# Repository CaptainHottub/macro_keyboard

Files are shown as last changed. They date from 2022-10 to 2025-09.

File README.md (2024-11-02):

# macro_keyboard

13-Key USB Macro Keyboard using the [KB2040 Kee Boar Driver][KB2040]

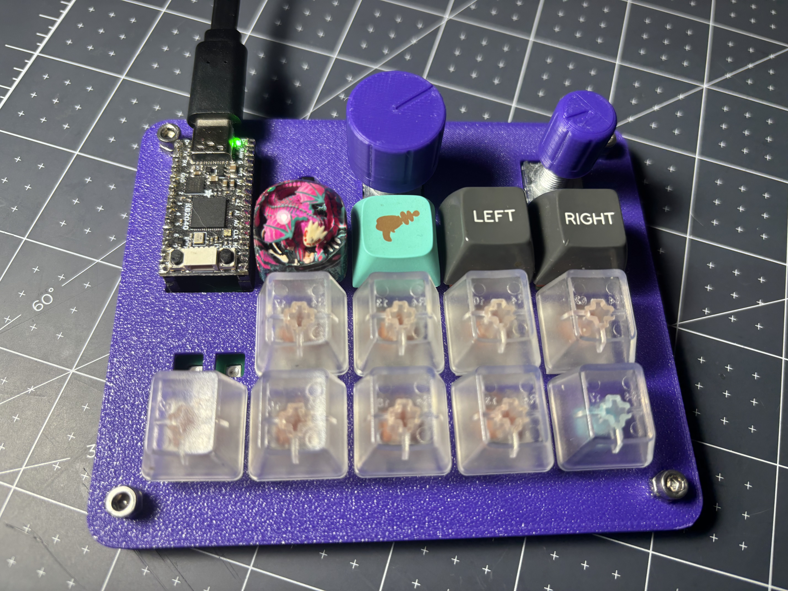
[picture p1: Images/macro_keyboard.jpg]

## Features
- The KB2040 MC communicates with the Python driver that runs on your computer
- The Python driver is fully customizable with the capability for application specific macros
- The Python driver allows for special scripts and complex macros. Anything you can think of.
- 3x4 Grid with 12 keys and 1 mode button
- 2 Rotary encoders with buttons
- 15 Addressable RGB LED backlights.
- South Facing LED and sockets
- KAILH hot swap sockets
- Unlimited layers and key combinations

## Getting Started
macro_keyboard V2.2x was designed to use the [Adafruit KB2040 - RP2040 Kee Boar Driver][KB2040], which has the same shape as the Arduino Pro Micro, so you could use any Arduino Pro Micro shaped MC in this macro_keyboard.
> If you use a different micro controller, you will have to change the pins in the MC code.

The KB2040 currently runs [CircuitPython](https://circuitpython.org/) version 8.2.9, but should work with anything newer.

#### Dependencies
If you are on Linux want to use the Media Controller macros you will you will need to install this package:
`sudo apt install libdbus-1-dev`

### KB2040 Setup
You will need to install CircuitPython on your KB2040 and to do so, follow Adafruit's excellent guide how to do exactly that: https://learn.adafruit.com/adafruit-kb2040/circuitpython

Once you get CircuitPython running on your KB2040, you will need to add a couple of libraries to it.
The Libraries that you will need are: 
- adafruit_hid
- adafruit_ticks.mpy
- neopixel.mpy

You can find them and the instructions to install them in the **CircuitPython Libraries** section of Adafruits KB2040 guide: https://learn.adafruit.com/adafruit-kb2040/circuitpython-libraries
You will find the libraries in the [**CircuitPython Library Bundle**](https://circuitpython.org/libraries)

Move the `code.py` file found in `src/Microcontroller/` onto the KB2040, then the KB2040 should do a soft reboot and start running that code.

### Python Driver Setup
The driver is a python script that connects to the comport that the KB2040 is connected to when plugged in via USB.  Once it connects to the comport, it waits for a "message" from the KB2040.  The "message" is sent when a button is released or an encoder changes position by turning.

The driver use [Python 3.12](https://www.python.org/downloads/)  or newer. Instruction on how to install Python can be found here: https://wiki.python.org/moin/BeginnersGuide/Download

To download the driver you can clone the repo or download a .zip of it:

    git clone https://github.com/CaptainHottub/macro_keyboard.git

You will need to install all the Python libraries listed in the `requirements.txt` file. Install using:

    pip install -r requirements.txt
In the `config.yaml` file you can find config options for:
Logging level, (INFO or DEBUG)

    logging: True 
    logging_level: DEBUG

Log Folder

    enter code log_folder: True
    log_folder_path: "" # The direct path
    log_folder_path_relative: "/logs" # relative from /macro_keyboard/

System Tray Icon

    system_tray_icon: True  
    # The direct path
    system_tray_icon_image_path: ""  
    # relative from /macro_keyboard/
    system_tray_icon_image_path_relative: "/Images/pythonIcon.ico"  

Connection Notification

    connected_notification: True  
    # in seconds
    notification_time: 2

Spotify auto start

    spotify_auto_start: False

Everything in the `config.yaml` file can be changed, you can add or remove whatever you want.

To run it you need to run the `macro_driver.py` in a terminal:

    python -u "/macro_keyboard/src/Driver/macro_driver.py"

### Assembling the PCB
Soldering all the components to the PCB can be a little difficult as I did chose some pretty small components, especially the LED's and diodes.
The production Gerber zip file for the PCB is in `src/PCB/Macro_PCB_2.2.x_Production_Gerber`, which you can submit to JLCPCB to get made.
The Bill Of Material is at  `/src/macro_keyboard_BOM.csv`. Most parts can be sourced from DigiKey.

There is a `macro_keyboard.step` that should help with any questions on component orientation.

**Bottom Mount Components**
- 13 KAILH Hot Swap Sockets
- 12 Diodes
- 15 SK6812-E RGB LEDS
- 330 OHM Resistor for LED Data Pin

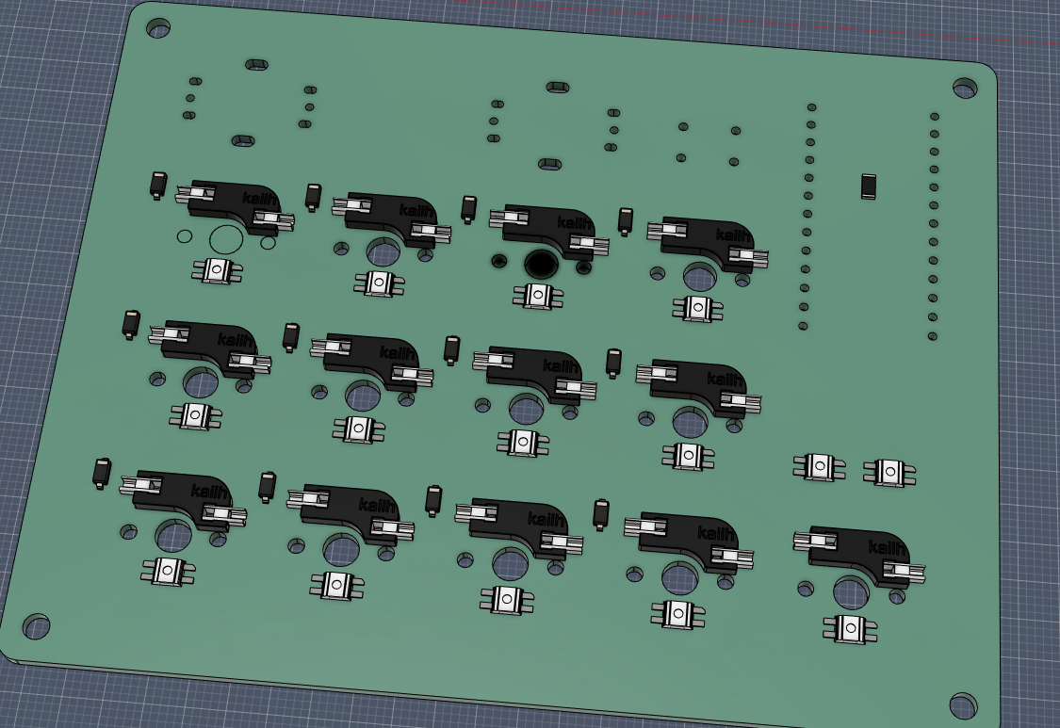
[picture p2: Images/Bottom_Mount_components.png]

> **Pay close attention to the position of the diode and especially the LED**

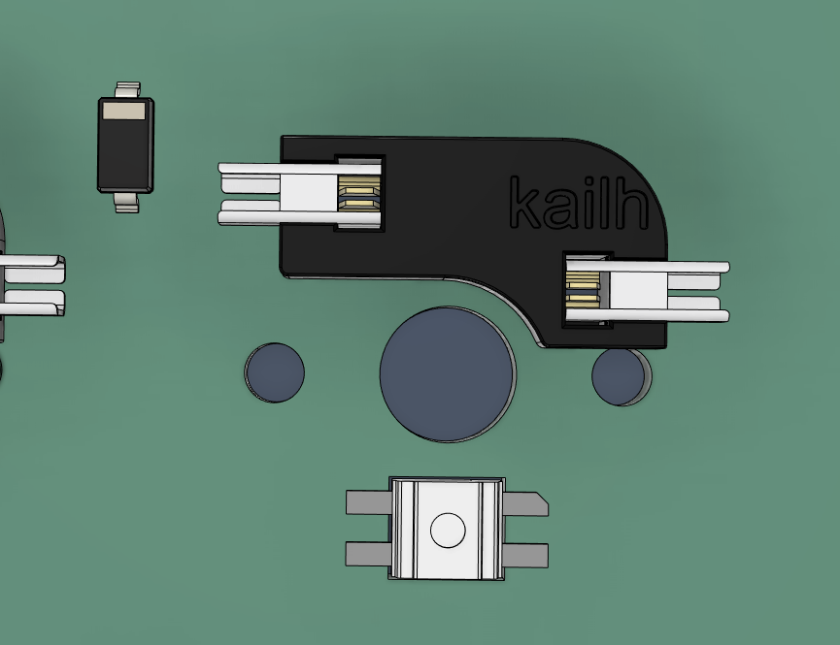
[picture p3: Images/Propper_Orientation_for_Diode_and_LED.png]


**Top Mount Components**
- KB2040
- 6x6mm Tactile Switch
- 2x Rotary Encoders (Is not necessary if you don't want it.)

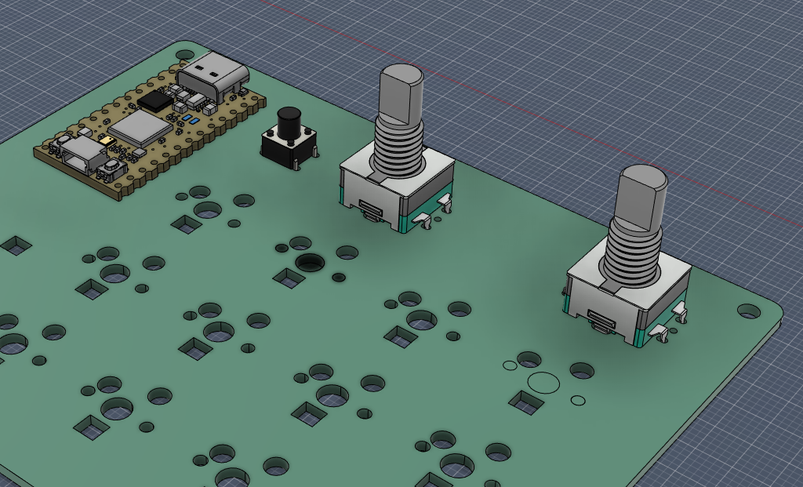
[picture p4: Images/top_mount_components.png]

If done properly any MX compatible key switch should just slide into each socket. The PCB is compatible with 3-pin and 5-pin key switches.

**Assembled PCB**

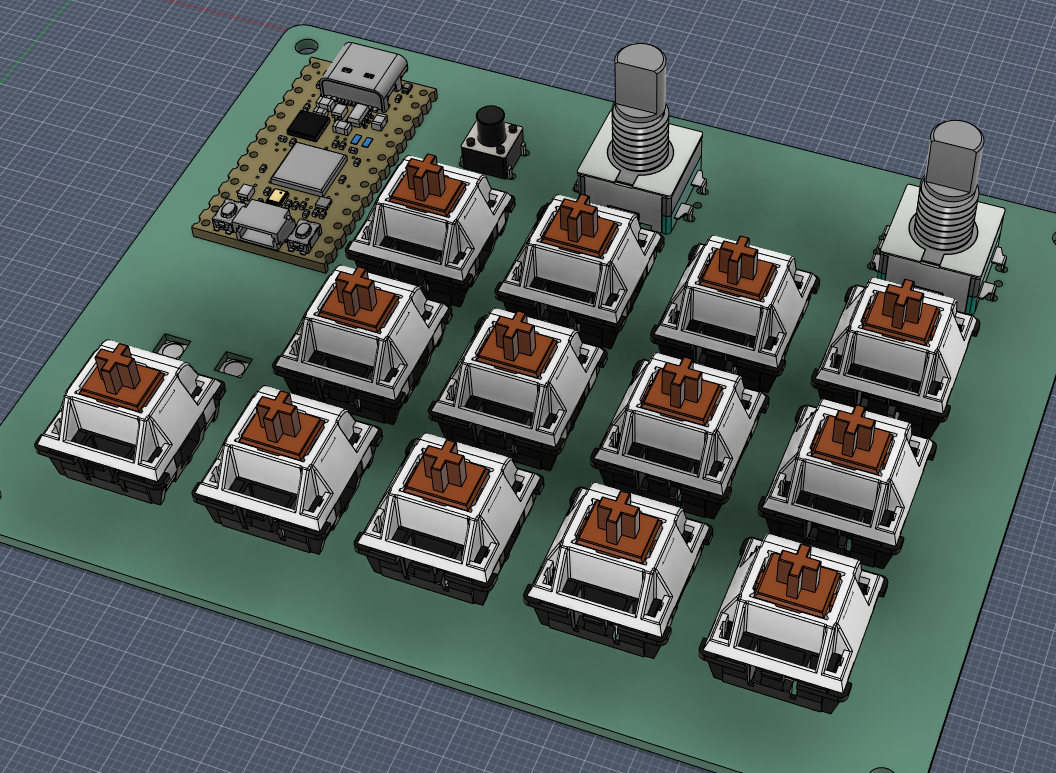
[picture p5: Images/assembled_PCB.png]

You should now have a fully assembles macro_keyboard that's ready to run. :)
It just needs a case.

### 3D Printed Case
Top half of the case

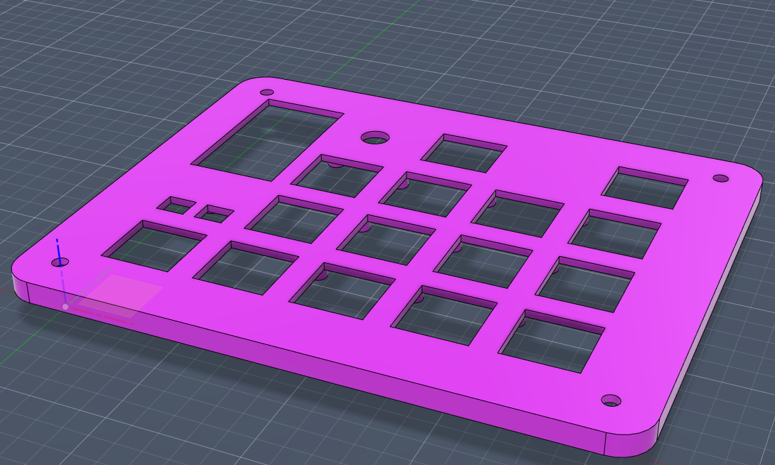
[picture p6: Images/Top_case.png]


The top half also serves as a plate that the keys snap into.

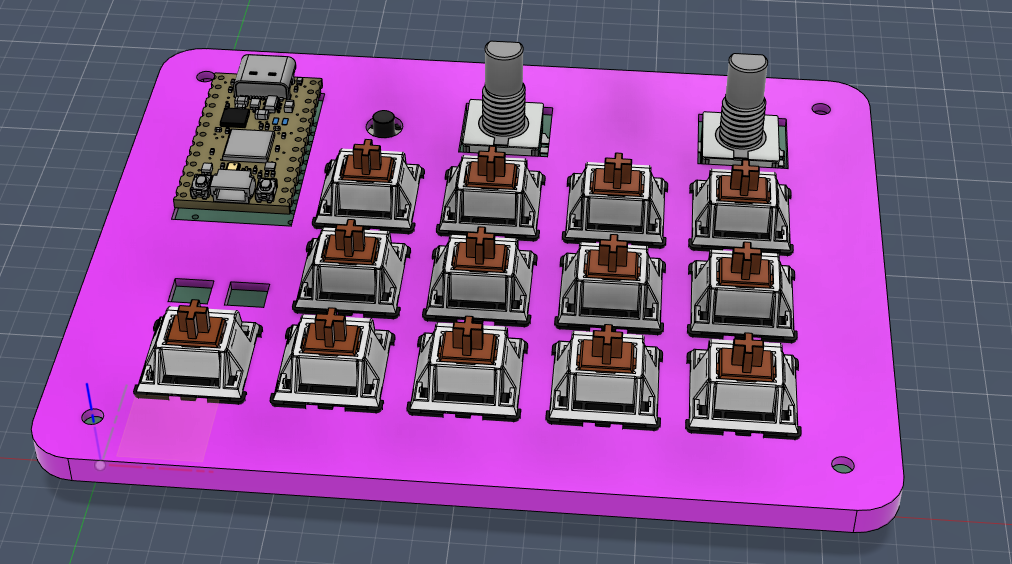
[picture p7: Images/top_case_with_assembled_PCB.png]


The bottom case on the left is called; `Bottom_Case_with_hole_V2.stl`, and the bottom case on the left is called; `Bottom_Case_No_Hole_V2.stl`

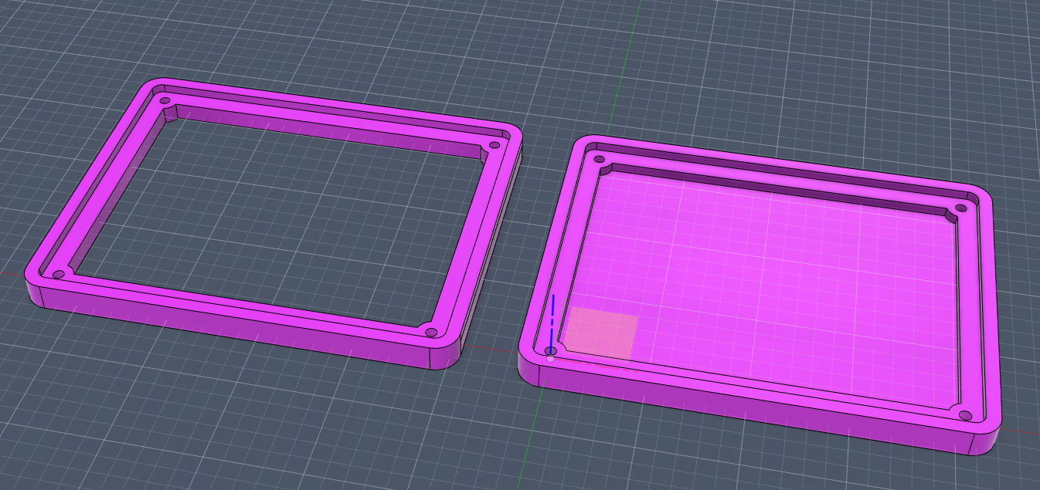
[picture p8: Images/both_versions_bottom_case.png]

The case uses 4 M3x12mm screws to secure it together, but it does support M3x10mm screws.

### Macro Examples
There are multiple macros that will work when you initially setup the driver. A couple of them are more complex then just keystrokes.
There are two groups of macro that I use the most, the first "group" is to control Spotify, the second "group" is to change and move apps across virtual desktops.

#### Spotify Macros
These macros use different code for different Operation Systems, because the Windows code wasn't compatible with Linux.
The prepacked macros involving Spotify are:

```python
####################################### Encoder 1 ########################################
match [app, encoder_data['Id'], encoder_data['Value'], layers]:
	case [_, 1, "RL", []]:	# Rotate Left
		logger.debug('VolumeDown')
		threading.Thread(target=Spotify.event_handler, args=('VolumeDown',)).start()
	case [_, 1, "RR", []]:	# Rotate Right
		logger.debug('VolumeUp')
		threading.Thread(target=Spotify.event_handler, args=('VolumeUp',)).start()
	case [_, 1, "RLB", []]:	# Rotate Left with Button
		logger.debug('Back5s')
		threading.Thread(target=Spotify.event_handler, args=('Back5s',)).start()
	case [_, 1, "RRB", []]:	# Rotate Right with Butotn
		logger.debug('Forward5s')
		threading.Thread(target=Spotify.event_handler, args=('Forward5s',)).start()

####################################### Buttons ########################################
match [app, mode, event_data['Button_id'], layers]:
	case [_, mode, 2, []]: # button 2
		logger.debug("Btn 2, no layers")
		threading.Thread(target=Spotify.press, args=()).start()
	case [_, mode, 2, [3, 4]]: # button 2 while button 3 and 4 are held
		logger.debug("Moves Spotify to the current virtual Desktop")
		threading.Thread(target=Spotify.move_spotify_window, args=('Current',)).start()    
	case [_, mode, 2, [3]]: # button 2 while button 3 is held
		logger.debug("Moves Spotify to the virtual Desktop on the left")
		threading.Thread(target=Spotify.move_spotify_window, args=('Left',)).start()    
	case [_, mode, 2, [4]]: # button 2 while button 4 is held
		logger.debug("Moves Spotify to the virtual Desktop on the right")
		threading.Thread(target=Spotify.move_spotify_window, args=('Right',)).start()   
	case [_, mode, 2, [1]]: # button 2 while button 1 is held
		logger.debug("Btn 2 and btn 1 as layer")
		threading.Thread(target=FireFox.press, args=()).start()
```
The macro I use the most is Spotify.press() which is attached to Button 2.
It works exactly like Apple's EarPods or there AirPods, where 1 press will play/pause, 2 presses will skip to the next song and 3 presses goes to the previous song.
On Linux it uses the `org.mpris.MediaPlayer2`  dbus interface to control media players.
On Windows it uses `pywinauto`  to connect to Spotify and send keyboard inputs.

## Inspiration
All of this was inspired by Ryan Bates and his [Macro Keyboard Video][video-inspiration]
[Website][retrobuilds2]

## License, Copyright, and Legal
All software and hardware designs in this repository are licensed under the [Creative Commons Attribution-NonCommercial 4.0 International][cc-by-nc] license.
[][cc-by-nc]

[cc-by-nc]: https://creativecommons.org/licenses/by-nc/4.0/
[cc-by-nc-image]: https://licensebuttons.net/l/by-nc/4.0/88x31.png

[retrobuilds]: http://www.retrobuiltgames.com/the-build-page/macro-keyboard-v2-0/ 
[retrobuilds2]: https://github.com/retrobuiltRyan/MacroKeyboardV2
[video-inspiration]: https://www.youtube.com/watch?v=IDlcxLQ1SbY
[KB2040]: https://www.adafruit.com/product/5302

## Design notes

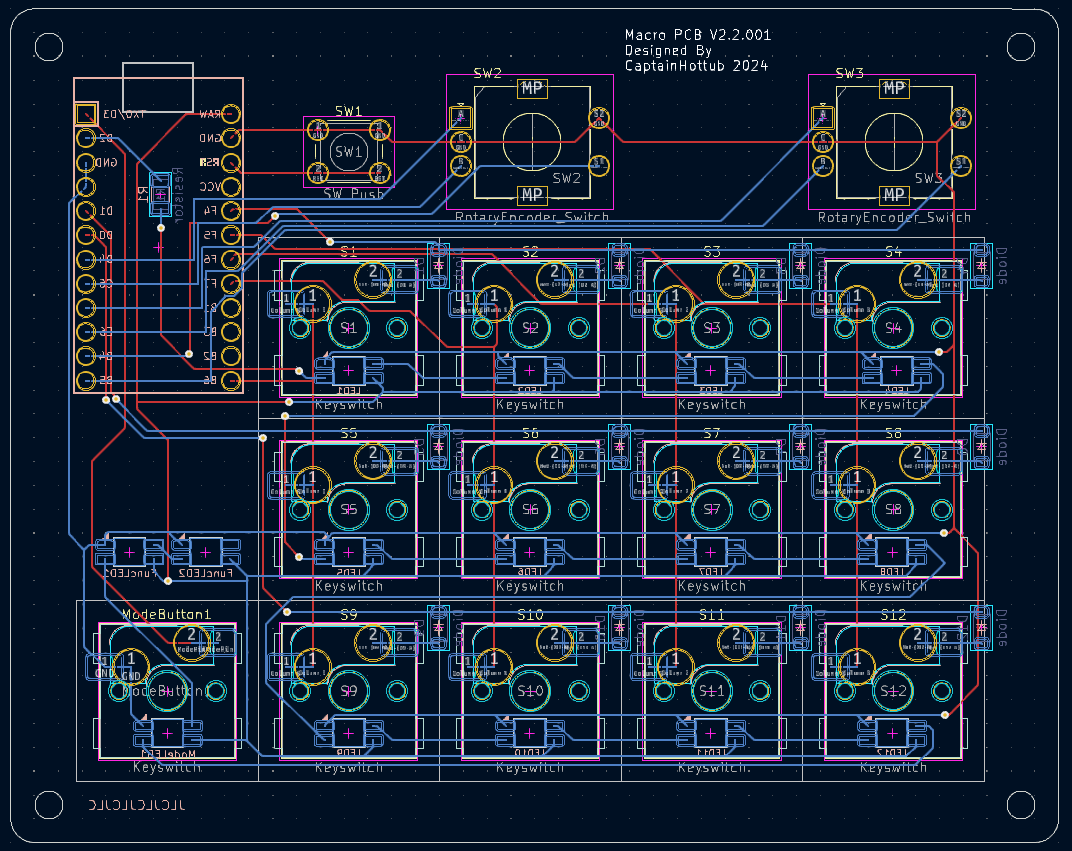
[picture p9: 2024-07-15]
Images/PCB_screenshot.png

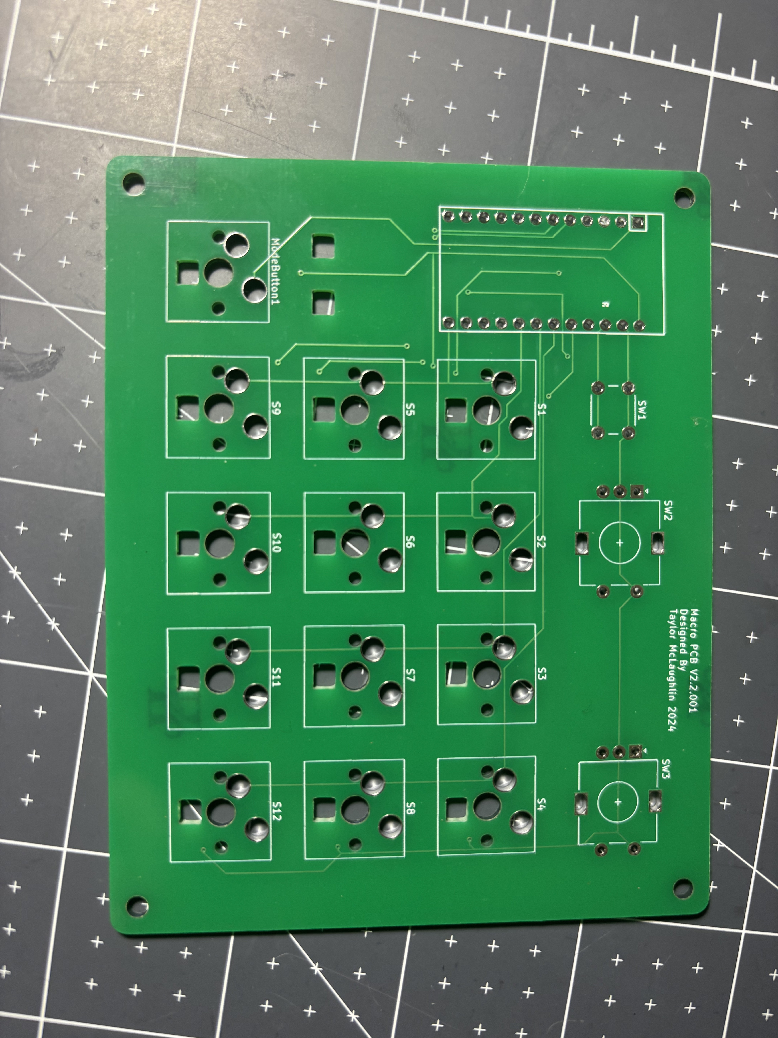
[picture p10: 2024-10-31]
Images/pcb.jpg

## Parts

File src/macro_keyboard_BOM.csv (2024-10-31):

Index | Quantity | Description | Vender | Vendor Part Number | Unit Price | Extended Price | Notes
1 | 1 | Adafruit KB2040 - RP2040 Kee Boar Driver | DigiKey | 1528-5302-ND | 13.14 | 13.14
2 | 1 | macro_keyboard v2.2.x PCB | -
3 | 13 | MX Cherry Keyswitch | - |  |  |  | 1 | 1 can be any MX compatible keyswitch
4 | 13 | Cherry MX Keycap | - |  |  |  | 1 | 2 any 6x6mm tactile switch will work
5 | 2 | Rotary encoder with Switch | DigiKey | 987-1398-ND | 4.62 | 9.24 |  | 3 This DigiKey listing comes in packs of 10
6 | 1 | SWITCH TACTILE SPST-NO 0.05A 12V | DigiKey | 679-2443-ND | 0.69 | 0.69 | 2 | 4 This DigiKey listing comes in packs of 20
7 | 2 | 1x12 Header 0.1” pitch | DigiKey | S6100-ND | 1.42 | 2.84
8 | 12 | Diode, small, 100V 300MA SOD123 | DigiKey | 1N4148W-13FDICT-ND | 0.15 | 1.8
9 | 1 | RES 330 OHM 5% 1/4W 1206 | DigiKey | RMCF1206JT330RCT-ND | 0.16 | 0.16
10 | 2 | SK6812-E RGB LEDS - 10PC | DigiKey | 1528-4960-ND | 4.62 | 9.24 | 3
11 | 1 | 3D Printed Case - Custom - | -
12 | 1 | KAILH MX HotSwap Sockets - 20PC | DigiKey | 1528-4958-ND | 7.27 | 7.27 | 4
13 | 4 | M3x10mm Machine Screws | -
 |  |  |  |  |  | 44.38

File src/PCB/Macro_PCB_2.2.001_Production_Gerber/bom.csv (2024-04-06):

Designator | Footprint | Quantity | Value | LCSC Part #
D1, D10, D11, D12, D2, D3, D4, D5, D6, D7, D8, D9 | Diode_SOD-123 | 12 | Diode
FuncLED1, FuncLED2, LED1, LED10, LED11, LED12, LED2, LED3, LED4, LED5, LED6, LED7, LED8, LED9, ModeLED1 | LED_SK6812MINI-E | 15 | LED_SK6812MINI-E
ModeButton1, S1, S10, S11, S12, S2, S3, S4, S5, S6, S7, S8, S9 | Hotswap_MX_Plated_1.00u | 13 | Keyswitch
R1 | 1206 | 1 | Resistor
SW1 | SW_PUSH_6mm_H7.3mm | 1 | SW_Push
SW2, SW3 | RotaryEncoder_Alps_EC11E-Switch_Vertical_H20mm | 2 | RotaryEncoder_Switch
U2 | Arduino_Pro_Micro | 1 | Arduino_Pro_Micro

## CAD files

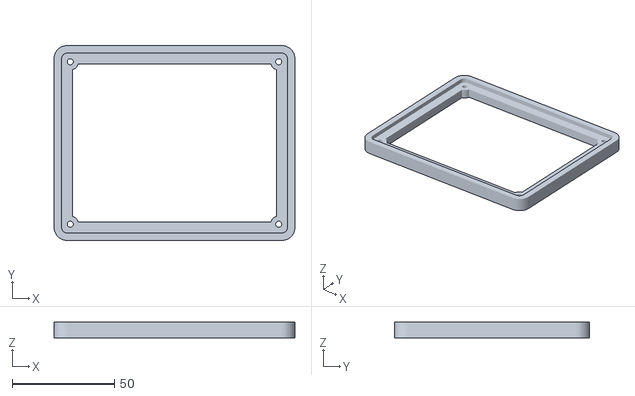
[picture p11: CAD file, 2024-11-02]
src/Case/Bottom_Case_with_hole_V2.stl
118.0 x 95.5 x 7.80

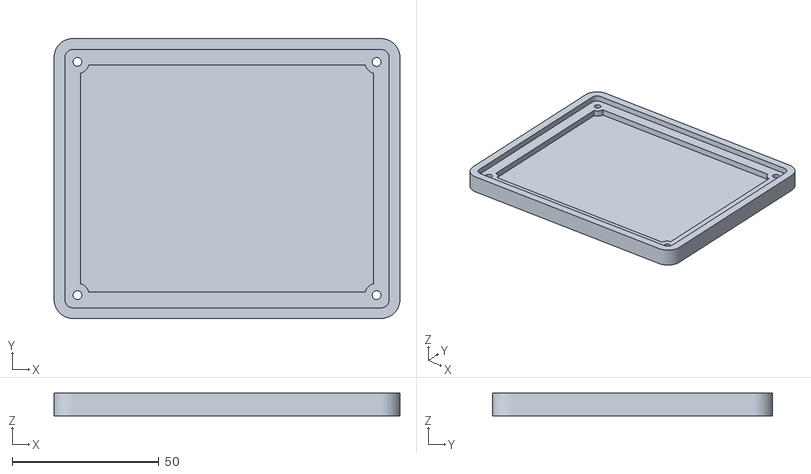
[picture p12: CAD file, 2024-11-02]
src/Case/Bottom_Case_No_Hole_V2.stl
118.0 x 95.5 x 7.80

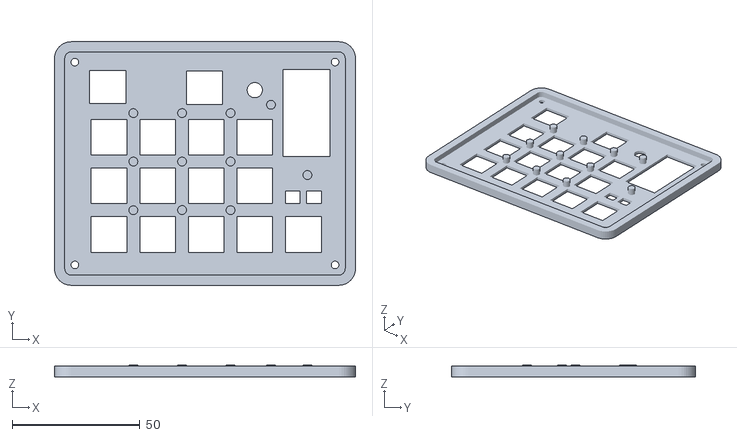
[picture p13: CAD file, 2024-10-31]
src/Case/Top_Plate_V3.stl
118.0 x 95.5 x 4.80

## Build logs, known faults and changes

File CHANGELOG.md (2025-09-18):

# Change Log

My macro_keyboard project

All notable changes to this project will be documented in this file.
 
The format is based on [Keep a Changelog](http://keepachangelog.com/)
<!-- and this project adheres to [Semantic Versioning](http://semver.org/). -->

## [2.3.009] - 2025-9-18
- Added a Soundboard Functionality
- Temporary fix for recursion limit crash
- Temporaraly disabled any function that gets window/app info, Wayland breaks alot of that.
- Slight update to requirments.txt

## [2.3.007] - 2024-11-02
- Added a new logging level called "trace", use only to show the most detailed info
- Implemented Spotify.move_spotify_window()
- Added pywin32==308 to the requirements.txt, its for Windows
- Updated README.md
- Added images for 3d printed case

## [2.3.005] - 2024-11-01
_MasterMediaController() now uses mpris2 package

## [2.3.004] - 2024-10-31
New Top Case that also acts as the plate for the keyswithes
Updated Photos

### Changed
- Changed the way the "focused_window_title" is aquired on linux, this should now work for factorio

## [2.3.003] - 2024-08-30
Driver shoudn't crash when Microcontroller is unpluged

## [2.3.002] - 2024-07-29
was messing with asyncio on microcontroller for the layer leds, It doesnt seem to run asynchronisly

### Changed
- lightshow when microcontrller boots

## [2.3.001] - 2024-07-14
IT SHOULD WORK THE SAME
You can now send text or json to the microcontroller.
Big changes to MacroDriver and the microcontroller code,
An LED now lights up when the pause state is true 

### Changed
- Changed the structure of MacroDriver:
- Moved Button_handler and Encoder_handler outside of MacroDriver

### Added
- You can now send text or json to the microcontroller.

## [2.2.137.b] - 2024-07-04
Improved Media Controllers for firefox and spotify.
Semi-update

### Changed
- Spotify and firefox controllers grab from the master controller.
- This would probably work with chrome too

### Added
- A MasterMediaController class, that has the press, and envent_handler stuff in it

## [2.2.136.b] - 2024-06-29
Requirements file
A media controller for FireFox, and TTS works

### Changed
- Modified the code that gets the app name, will have to make it better.
- Pyclip is replacing Pyperclip, because Pyperclip wasn't in macros, only in that file. IDK why
- Azure TTS now works on linux.

### Added
- Requirements file
- A media controller for FireFox
- spotify_auto_start setting to config. when 1, spotify will automaticaly start if you try and interact with it.
- libreOffice_font_size_up() and libreOffice_font_size_down(). does exactly what its called

## [2.2.135.b] - 2024-06-27
I belive most of the macros will work on linux.

### Changed
- The Azure TTS only works on Windows, I cant get it to work right now.
- ButtonMode() now prints in the console instead of creating a window, it was crashing on the second time being pressed on linux (this is a temp solution) 

## [2.2.132.b] - 2024-06-17

If spotify isnt running it will start, when _SpotifyController is called

## [2.2.131.b] - 2024-06-13

Major changes to file structure

Tools.py moved to macros.py
and the os specific function got moved to there own files.
move_desktop and spotify controller are the only functions that are currently cross platform
_Image_to_text2 now works on linux.

Azure speechsdk is broken for some reason

### Changed
- Getting the focused_window name is more reliable

## [2.2.125.b] - 2024-06-09

### Added
- Added some logs when certain things are initialized

### Changed
- The System Tray Icon should now show the full version.

## [2.2.124.b] - 2024-06-09

It should be easier to test macros now.
added testing.py, that will ask for an input and it will send said input to MacroDriver.Event_handler()

### Added
- testing.py

### Changed
- button, event_type, layers and app are no longer globals variables
- tools.change_desktop() should now be faster

## [2.2.123.b] - 2024-06-08

It now works on linux and windows.
There are still some bugs, like the Azure speech stuff doesnt work

## [2.2.121.b] - 2024-06-08

First port to linux

### Added
- a config file: config.yml
- media_controller.py

### Changed
- A lot of stuff got changed.
- main.py got merged with macro_driver.py
- logger.py was renamed to setup.py
- the media controllers got moved to media_controller.py
- The Azure speech stuff will not work on linus due to a big.

## [2.2.111] - 2024-06-07

Removed unessisary comments

### Changed
- Removed unessisary comments
- chromeAudioControl and mediaTimerV2

## [2.2.110] - 2024-06-07
 
Brainstorming in TODO
Minor changes

### Added

- Youtube Music Controller Class
- New function that sets the desktop as focused

### Changed
- Changed the match case statment variable positions in Button_handlerV3
- get_focused() returns the handle of that window.

- chromeAudioControl has been updated to a ChromeController class
- moveAppAccrossDesktops() only accepts window handles.
- Removed the unecisary Ctypes stuff in tools. (except for the VDA stuff)
- Modified get_processes()
- Removed hwndGetter().

## [2.2.108] - 2024-04-22
 
chromeAudioControl is more reliable

### Changed
- I believe I made chromeAudioControl more reliable

## [2.2.107] - 2024-04-19
 
Changed how spotify controls work

### Added

- Added a zoomin and zoomout macro for LibreOffice Draw

### Changed
- N/A

### Fixed
- N/A

## [2.2.105] - 2024-04-19
 
Changed how spotify controls work

### Added

- SpotifyController Class
  All the spotify specific controlls are now in that class.
  I haven't written any documentation for it yet.

- MediaTimer is a class now
  It works the same as before.
  Again, haven't written documentation yet

- The taskbar icon and the logger now get the version from the CHANGELOG.md file

### Changed
- Removed most of the VirtualDesktopAccessor.dll Functions.
 
- Commented out spotifyControl and moveSpotifyAccrossDesktops functionns

### Fixed
- N/A

## [2.2.101] - 2024-04-18
 
First CHANGELOG commit
 
### Added

- moveAppAccrossDesktops and moveSpotifyAccrossDesktops were added
  Now you can move Spotify across desktops, instead of just to the current one, I also works for the focused app.

- launchApp
  It lets you input the name of an app or the path to it as a argument and it will try and launch it.
  Its currently only used to launch Spotify.

### Changed
- Commented out most of the VirtualDesktopAccessor.dll Functions.
 
- In mediaTimerV2, the timer function now calls runAfterTimer, and that calls the function you want

- spotifyControl, will now launch spotify if it is not running
### Fixed
- N/A

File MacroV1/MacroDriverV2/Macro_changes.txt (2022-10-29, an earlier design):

##############   V2_3   ##############   NOT IMPLEMENTED YET
added get_stats function,
it gets mouse position, 
the hwnd, the name and fullscreen or not of the focused app
can be toggled into a while loop if loop=True in args. 

Modified Button_handler func
now uses multiple match case, stacked together.

A layer is the name of an app that you want to have specific macros for.
app = stats["focused_app"][0]

match [app, button.split()]:
    # the first case whre app is _ means universal macros,
    # They will happen everytime if the button is pressed
    case [_, ("btn", mode)]:
        do something

    # the case's where app is defined as str of name of the app
    # this will happen when the app focused is "Visual Studio Code" and the button is 5
    case ["Visual Studio Code", ("5", mode)]:
        do something

    # the last case's where app is _, is default macros
    # so if i press button 11, and it is not defined above, but is defined bellow,
    # it will execute
    case [_, ("btn", mode)]:
        do something

##############   V2_2.1   ##############
Updated playPause(), now at V5
Also moved it into spotify().

PlayPause now gets the parent PID, so it only returns one item, so no need to loop through them all to find the right one.
Removed Set Focus or wtv its called, is now part of PlayPause

Changed Code for System Tray Icon.
I did this because it didnt work with the new icon

Was using infi.systray.SysTrayIcon  
Now using pystray and PIL.Image

Changed Icon path from "C:\Coding\Arduino Stuff\Projects\Arduino Python\MacroV2\python.ico" to:
"C:\Coding\Arduino Stuff\Projects\macro_keyboard\MacroV2\pythonIcon.ico"
And using Image.open() to open the image before

The following was Removed:
    systray = SysTrayIcon(icon_path, "Python Macro", on_quit=on_quit) # little icon in bottom right
    systray.start()
    
    and "SysTrayIcon.shutdown" in def on_quit():

It was replaced with:     
    twrv = Thread(target = sysIcon).start()

    and 
    def sysIcon():
        systray = pystray.Icon("Neural", image, menu=pystray.Menu(
            pystray.MenuItem("Quit", on_quit)
        ))
        systray.run()

"SysTrayIcon.shutdown" in on_quit() was replaced with:
systray.stop()

##############   V2_2   ##############
Changed icon_path from "C:\Coding\Python\pythonScript.ico" to:
"C:\Coding\Arduino Stuff\Projects\Arduino Python\MacroV2\python.ico"

The following was moved into if __name__ == "__main__":
    DEBUG = 0  # 0 for off 1 for DEBUG logs on
    logger_setup(DEBUG)
    from funcs import log

Importing all from funcs
From funcs importing:
    import contextlib
    import threading
    from threading import Thread
    import warnings
    import psutil
    import pyautogui
    import os, win32gui, win32process
    import pyperclip
    from pywinauto import Application
    from ctypes import windll
    from PIL import ImageGrab
    import logging
    import time

Removed: 
    #import time
    #import pyautogui
    #from threading import Thread
    #import funcs
    #import timeit

##############   V2_3   ##############
Removed stuff
def Button_handler_v1(button):
    get_stats()

    app = stats["focused_app"][0]

    ###### Macros that work for all modes
    match button.split():
        case ["2", mode]: # pause song spotify
            log.debug("pause song spotify")
            spotify()
            return
        case ["3", mode]:    # move desktop left
            log.debug("move desktop left")
            twrv = Thread(target = Change_desktop, args=('left',)).start()
            return

        case ["4", mode]:     # move desktop right   
            log.debug("move desktop Right")
            twrv = Thread(target = Change_desktop, args=('right',)).start()
            return

    match [app]:
        case ['Visual Studio Code']:
            match button.split():
                case ["5", mode]:    # run code in Vs code
                    pyautogui.hotkey('ctrl', 'alt', 'n')

                case [btn, mode]:
                    print(f"button {btn} pressed on Visual Studio Code")    

        case _:
            match button.split():
                ###### Macros that work for all modes
            
                case [btn, mode]:
                    print(f"button {btn} pressed on universal layer")

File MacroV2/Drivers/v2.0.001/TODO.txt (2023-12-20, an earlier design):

Add a requirements file 

MOST of This is outdated
Merge this todo with the v2.1.001 Todo

Merge the pause feature to V3.2

I think I have recreated the code, it is in should_work.ino 
Will just need to change macro_drive code to increment mode when received str is "Mode Button"
And change the string parsing
https://wokwi.com/projects/361758088356902913

Recreate or find the code that is on the arduino, If I find it change it so that it only handles what button was pressed.
move the button mode stuff to the driver script.
I CAN.  Find out if I can send RGB information to the Arduino from the driver script.

I want to redesign the macro pcb so that i can use the typical hotswap socekts and so 5 pin switches fit too. 
North facing LEDs.
I want to put LEDs on it to and maybe add a 4th row of keys so it can be a 4x4 macro pad.

Macro improvements

Look in code for global variables there. If there are maybe use the class. Idk. 
Spotify thing. Make it a class called controller. 
Or not maybe. 

Move Mode variable to driver script.
Remove it from arduino code.

Add RGB features
We will need to add RGB LEDs to PCB before RGB features

If I had a RGB features I don’t wanna have to flash the Arduino firmware every time I change the RGB colours or stuff

Currently The Arduino sends the button that was pressed to the driver. 
I want to be able to send RGB information to the Arduino
So like when The driver connected to the Arduino it sends like a string of text that has come what colours are on what 
button and maybe I’m like if it’s rainbow effect or if I press the button it’ll glow on the outside(kinda have my keyboard is set up now)

Change code on The Arduino so that it only handles what button was pressed and RGB

MAYBE
try and transition all pyautogui keyboard funtions to custom_keyboard
add a write function to custom_keyboard

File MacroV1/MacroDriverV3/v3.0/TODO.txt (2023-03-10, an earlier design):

update image to text, so it presses Win+shift+s
then waits until mouse up to save image and do tts
when I press esc have it stop, and have it account for close snippet(the x button)

Add code that will check if there is a folder with macro version for logs.
If none add one.
When I right click on the taskbar icon, I want there to be a toggle button
When On I want it to open a console window that will print the debug and error messages to it
and when off it goes away.

When I right click on the taskbar icon, I want there to be a toggle button
When On I want it to open a console window that will print the debug and error messages to it
and when off it goes away.

try and transition all pyautogui keyboard funtions to custom_keyboard
add a write function to custom_keyboard

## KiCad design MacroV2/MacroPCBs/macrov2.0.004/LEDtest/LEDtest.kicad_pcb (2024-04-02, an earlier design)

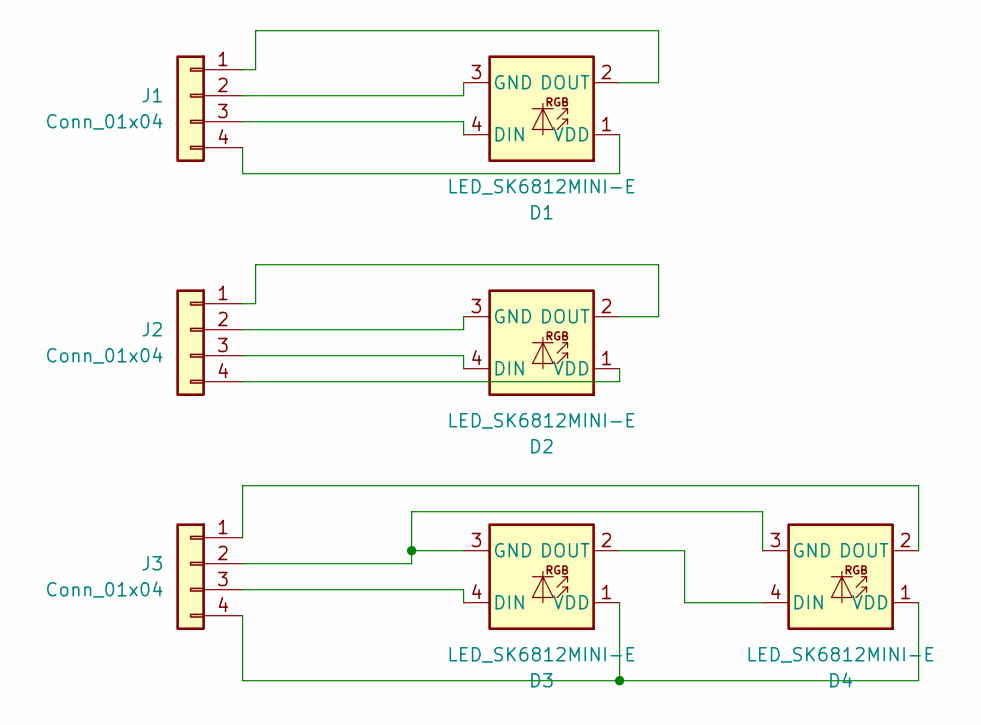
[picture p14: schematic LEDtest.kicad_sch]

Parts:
D1, D2, D3, D4: LED_SK6812MINI-E
J1, J2, J3: Conn_01x04; PinHeader_1x04_P2.54mm_Vertical

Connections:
unnamed: D1.4 (DIN), J1.3
unnamed: D1.2 (DOUT), J1.1
unnamed: D1.3 (GND), J1.2
unnamed: D1.1 (VDD), J1.4
unnamed: D2.4 (DIN), J2.3
unnamed: D2.2 (DOUT), J2.1
unnamed: D2.3 (GND), J2.2
unnamed: D2.1 (VDD), J2.4
unnamed: D3.4 (DIN), J3.3
unnamed: D3.2 (DOUT), D4.4 (DIN)
unnamed: D3.3 (GND), D4.3 (GND), J3.2
unnamed: D3.1 (VDD), D4.1 (VDD), J3.4
unnamed: D4.2 (DOUT), J3.1

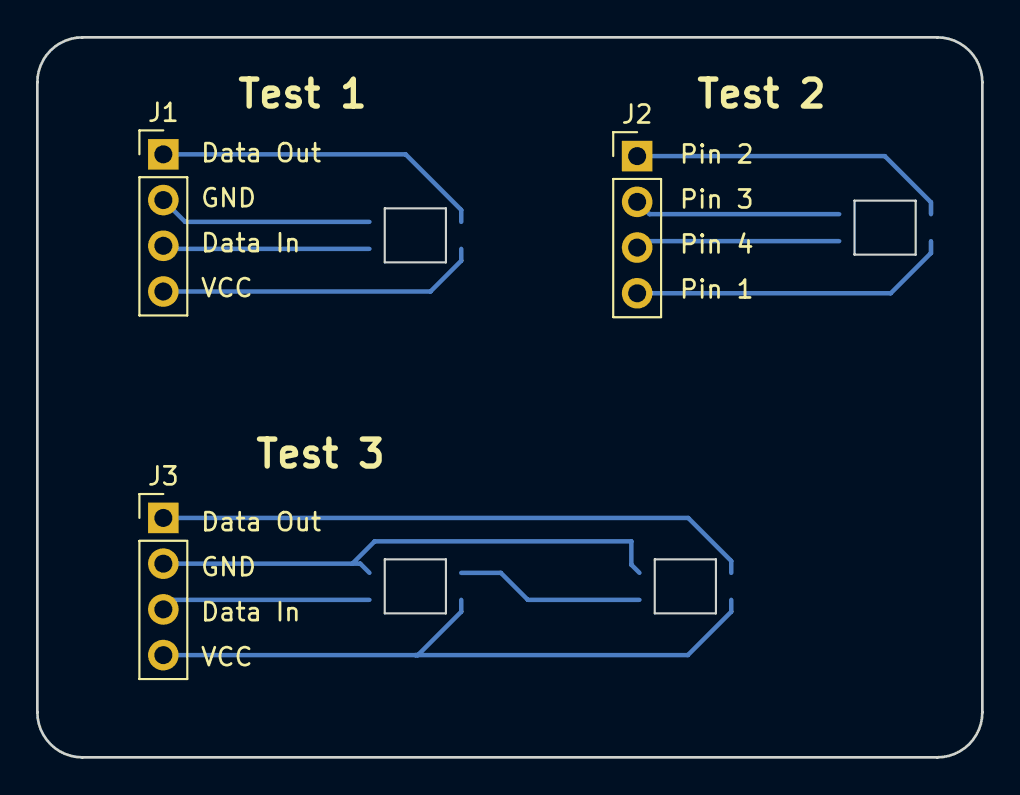
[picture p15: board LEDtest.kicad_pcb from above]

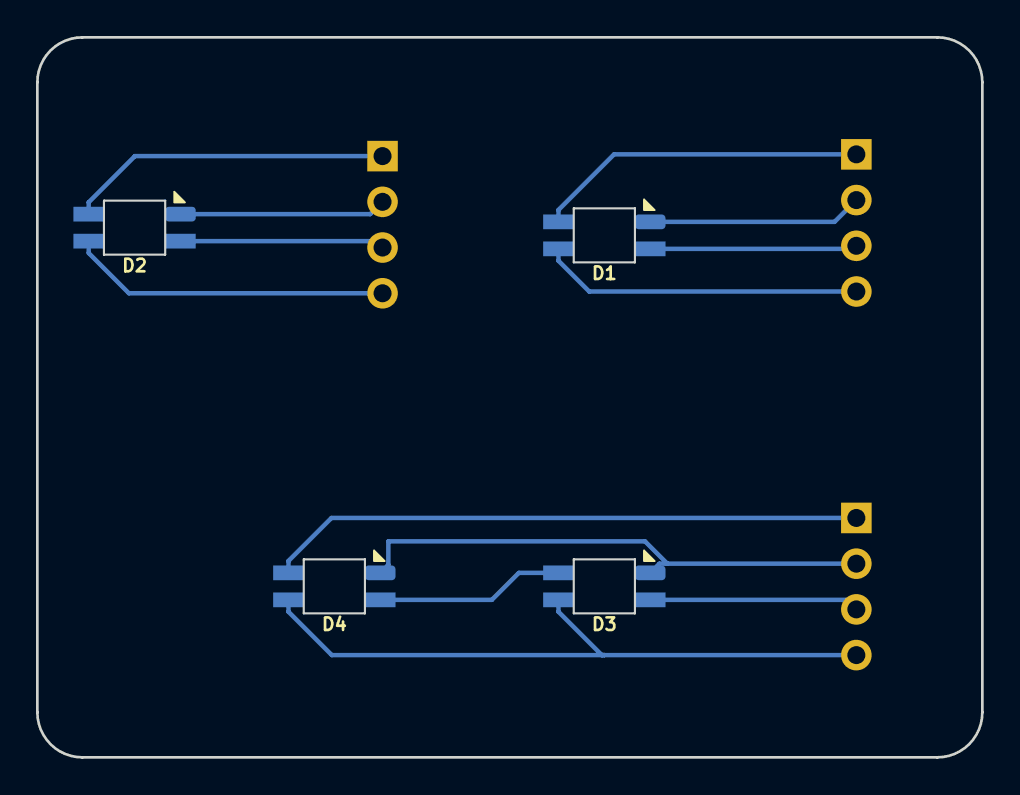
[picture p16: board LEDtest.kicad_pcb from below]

Board: 2 copper layers, 52.5 x 40.0 mm, 7 parts (4 on the bottom side), 13 nets.

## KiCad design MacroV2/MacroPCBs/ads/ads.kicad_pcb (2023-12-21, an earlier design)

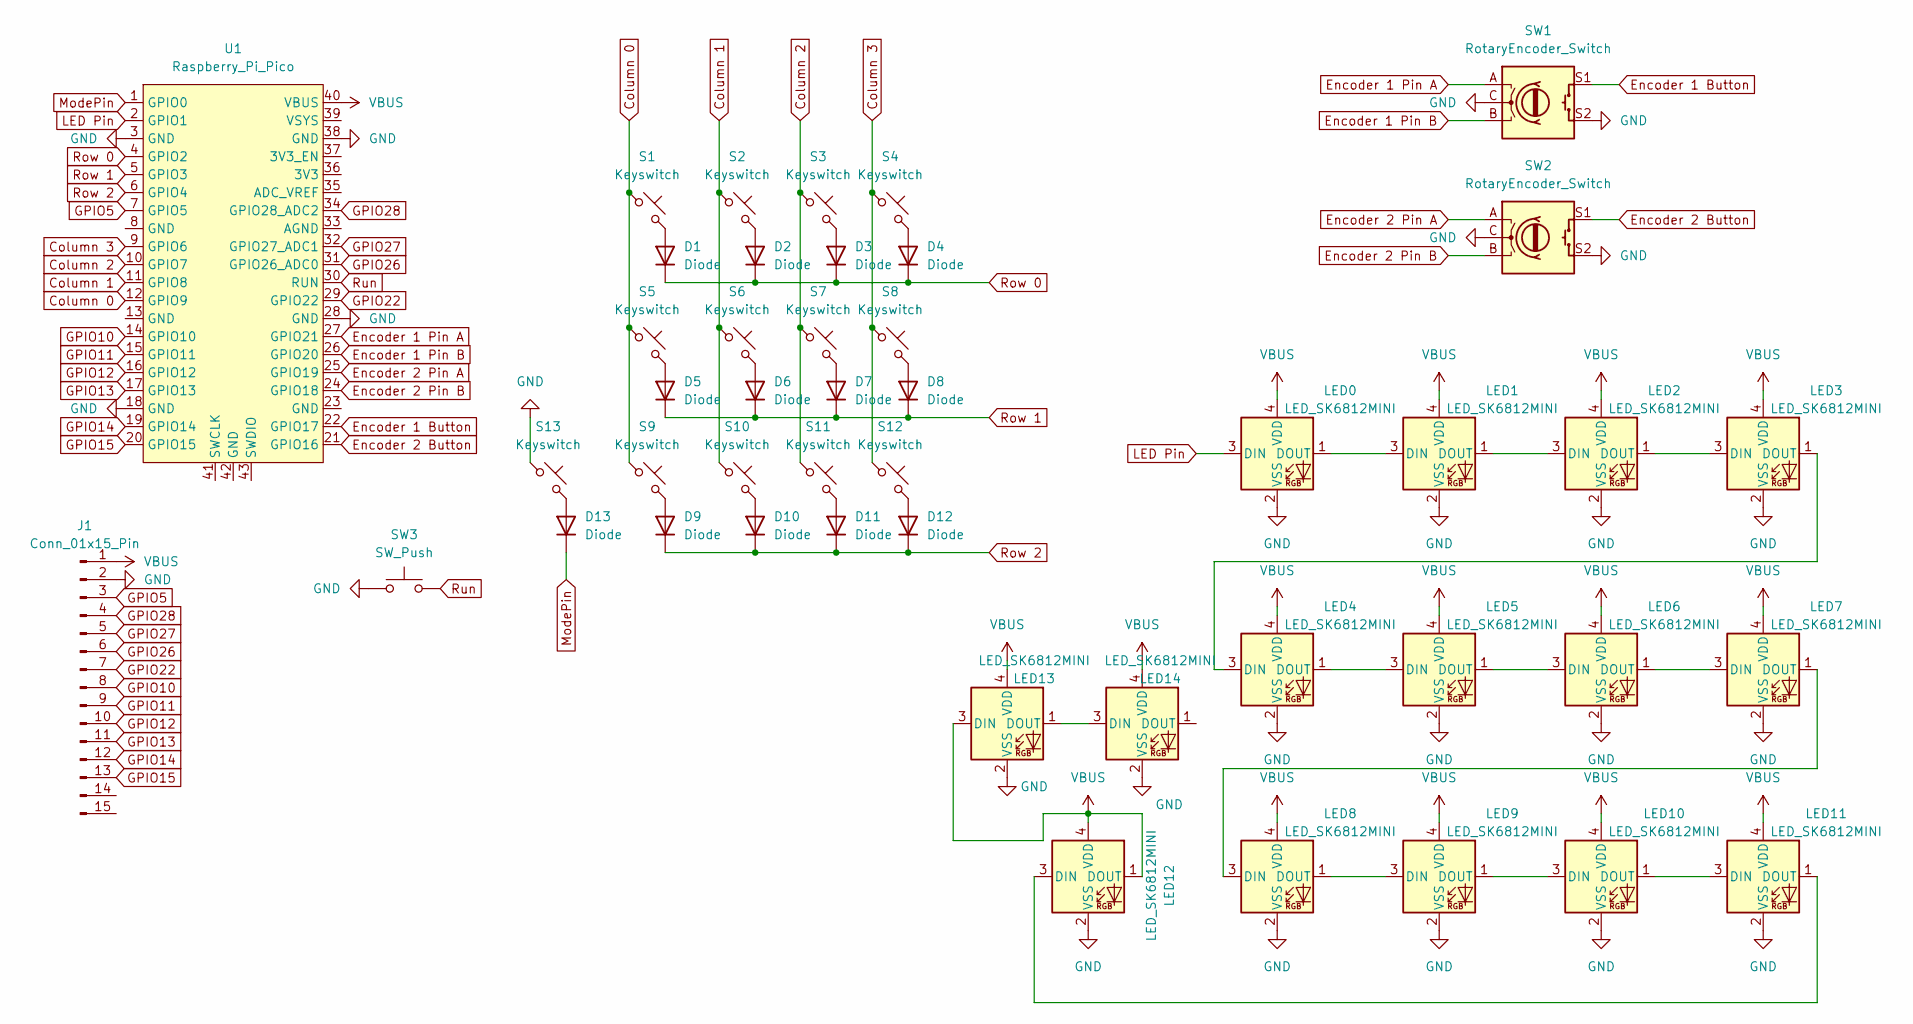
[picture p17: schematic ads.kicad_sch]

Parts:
D1, D2, D3, D4, D5, D6, D7, D8, D9, D10, D11, D12, D13: Diode; Diode_SOD-123
J1: Conn_01x15_Pin; PinHeader_1x15_P2.54mm_Vertical
LED0, LED1, LED2, LED3, LED4, LED5, LED6, LED7, LED8, LED9, LED10, LED11, LED12, LED13, LED14: LED_SK6812MINI
S1, S2, S3, S4, S5, S6, S7, S8, S9, S10, S11, S12, S13: Keyswitch; Hotswap_MX_Plated_1.00u
SW1, SW2: RotaryEncoder_Switch; RotaryEncoder_Alps_EC11E-Switch_Vertical_H20mm
SW3: SW_Push; SW_PUSH_6mm_H7.3mm
U1: Raspberry_Pi_Pico

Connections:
Column 0: S1.1, S5.1, S9.1, U1.12 (GPIO9)
Column 1: S2.1, S6.1, S10.1, U1.11 (GPIO8)
Column 2: S3.1, S7.1, S11.1, U1.10 (GPIO7)
Column 3: S4.1, S8.1, S12.1, U1.9 (GPIO6)
Encoder 1 Button: SW1.S1, U1.22 (GPIO17)
Encoder 1 Pin A: SW1.A, U1.27 (GPIO21)
Encoder 1 Pin B: SW1.B, U1.26 (GPIO20)
Encoder 2 Button: SW2.S1, U1.21 (GPIO16)
Encoder 2 Pin A: SW2.A, U1.25 (GPIO19)
Encoder 2 Pin B: SW2.B, U1.24 (GPIO18)
GND: J1.2, LED0.2 (VSS), LED1.2 (VSS), LED2.2 (VSS), LED3.2 (VSS), LED4.2 (VSS), LED5.2 (VSS), LED6.2 (VSS), LED7.2 (VSS), LED8.2 (VSS), LED9.2 (VSS), LED10.2 (VSS), LED11.2 (VSS), LED12.2 (VSS), LED13.2 (VSS), LED14.2 (VSS), S13.1, SW1.C, SW1.S2, SW2.C, SW2.S2, SW3.1, U1.3 (GND), U1.18 (GND), U1.28 (GND), U1.38 (GND)
GPIO5: J1.3, U1.7 (GPIO5)
GPIO10: J1.8, U1.14 (GPIO10)
GPIO11: J1.9, U1.15 (GPIO11)
GPIO12: J1.10, U1.16 (GPIO12)
GPIO13: J1.11, U1.17 (GPIO13)
GPIO14: J1.12, U1.19 (GPIO14)
GPIO15: J1.13, U1.20 (GPIO15)
GPIO22: J1.7, U1.29 (GPIO22)
GPIO26: J1.6, U1.31 (GPIO26_ADC0)
GPIO27: J1.5, U1.32 (GPIO27_ADC1)
GPIO28: J1.4, U1.34 (GPIO28_ADC2)
LED Pin: LED0.3 (DIN), U1.2 (GPIO1)
ModePin: D13.1 (K), U1.1 (GPIO0)
unnamed: D1.2 (A), S1.2
unnamed: D2.2 (A), S2.2
unnamed: D3.2 (A), S3.2
unnamed: D4.2 (A), S4.2
unnamed: D5.2 (A), S5.2
unnamed: D6.2 (A), S6.2
unnamed: D7.2 (A), S7.2
unnamed: D8.2 (A), S8.2
unnamed: D9.2 (A), S9.2
unnamed: D10.2 (A), S10.2
unnamed: D11.2 (A), S11.2
unnamed: D12.2 (A), S12.2
unnamed: D13.2 (A), S13.2
unnamed: LED0.1 (DOUT), LED1.3 (DIN)
unnamed: LED1.1 (DOUT), LED2.3 (DIN)
unnamed: LED2.1 (DOUT), LED3.3 (DIN)
unnamed: LED3.1 (DOUT), LED4.3 (DIN)
unnamed: LED4.1 (DOUT), LED5.3 (DIN)
unnamed: LED5.1 (DOUT), LED6.3 (DIN)
unnamed: LED6.1 (DOUT), LED7.3 (DIN)
unnamed: LED7.1 (DOUT), LED8.3 (DIN)
unnamed: LED8.1 (DOUT), LED9.3 (DIN)
unnamed: LED9.1 (DOUT), LED10.3 (DIN)
unnamed: LED10.1 (DOUT), LED11.3 (DIN)
unnamed: LED11.1 (DOUT), LED12.3 (DIN)
unnamed: LED13.1 (DOUT), LED14.3 (DIN)
Row 0: D1.1 (K), D2.1 (K), D3.1 (K), D4.1 (K), U1.4 (GPIO2)
Row 1: D5.1 (K), D6.1 (K), D7.1 (K), D8.1 (K), U1.5 (GPIO3)
Row 2: D9.1 (K), D10.1 (K), D11.1 (K), D12.1 (K), U1.6 (GPIO4)
Run: SW3.2, U1.30 (RUN)
VBUS: J1.1, LED0.4 (VDD), LED1.4 (VDD), LED2.4 (VDD), LED3.4 (VDD), LED4.4 (VDD), LED5.4 (VDD), LED6.4 (VDD), LED7.4 (VDD), LED8.4 (VDD), LED9.4 (VDD), LED10.4 (VDD), LED11.4 (VDD), LED12.1 (DOUT), LED12.4 (VDD), LED13.3 (DIN), LED13.4 (VDD), LED14.4 (VDD), U1.40 (VBUS)

Board: 2 copper layers, 46 parts (13 on the bottom side), 55 nets, no tracks yet.

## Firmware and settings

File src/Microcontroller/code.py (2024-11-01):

"""
Listens to the REPL port, without using the usb_cdc module.
Receives color information and displays it on the NEOPIXEL.
Receives blink command and blinks once.
Sends button release and encoder position change.

https://github.com/Neradoc/circuitpython-sample-scripts/blob/main/usb_serial/README.md
https://github.com/Neradoc/circuitpython-sample-scripts/blob/main/usb_serial/serial_exchange_repl-code.py
"""

import board
import digitalio
import json
import time
import supervisor
import sys
import keypad
import neopixel
import rotaryio

# import asyncio          # https://github.com/adafruit/Adafruit_CircuitPython_asyncio/tree/main
from rainbowio import colorwheel
################################################################
# select the serial REPL port
################################################################

serial = sys.stdin

################################################################
# init board's LEDs for visual output
# replace with your own pins and stuff
################################################################
onboard_pix = neopixel.NeoPixel(board.NEOPIXEL, 1)

pixel_pin = board.RX
num_pixels = 15
pixels = neopixel.NeoPixel(pixel_pin, num_pixels, brightness=0.1, auto_write=False)



encoder_1_button = digitalio.DigitalInOut(board.D8)
encoder_1_button.direction = digitalio.Direction.INPUT
encoder_1_button.pull = digitalio.Pull.UP
encoder_1_button_state = None
#encoder_1 = rotaryio.IncrementalEncoder(board.D4, board.D5)
encoder_1 = rotaryio.IncrementalEncoder(board.D5, board.D4)
encoder_1_last_position = 0


encoder_2_button = digitalio.DigitalInOut(board.D9)
encoder_2_button.direction = digitalio.Direction.INPUT
encoder_2_button.pull = digitalio.Pull.UP
encoder_2_button_state = None
#encoder_2 = rotaryio.IncrementalEncoder(board.D6, board.D7)
encoder_2 = rotaryio.IncrementalEncoder(board.D7, board.D6)
encoder_2_last_position = 0


keys = keypad.KeyMatrix(
    row_pins=(board.A3, board.D2, board.D3),
    column_pins=(board.D10, board.A0, board.A1, board.A2),
    columns_to_anodes=True,
    max_events = 10
)

ModeButton = keypad.Keys((board.TX,), value_when_pressed=False, pull=True)
Mode = 1

# held_keys = [0, 0, 0, 0, 0, 0, 0, 0, 0, 0, 0, 0, 0]

held_keys_dict={}

# def msgContructor2(event, type, encoder_button: int = 0, encoder_pos_change: int = 0 ):
#     data_out = {}
#     # data_out["buttons"] = [{"status": "RELEASED", "id": button_id}]
#     if type == "mode": 
#         #check if it has a timestamp and if diff <(less then) 0.250:  then send: 00010000 (0001 = release 0000 = mode)

#         if held_keys[-1]:  # I dont think this needs to be here
    
#             diff = (supervisor.ticks_ms() - held_keys[-1])/1000
#             if diff < 0.250:   # if its less then
#                 # data_out["buttons"] = [{"id": hex(0)}]
#                 # data_out["buttons"] = [{"id": '0x0'}]
#                 # data_out["button_id"] =  '0x0'
#                 data_out["Button_id"] =  'Mode'
#             else:
#                 held_keys[-1]  = 0
#                 return 

#         held_keys[-1]  = 0
    
#     elif type == "button":
#         # key_timestamp = held_keys[MatrixEvent.key_number]
#         key_timestamp = held_keys[event.key_number]

#         if key_timestamp:
#             diff = (supervisor.ticks_ms() - key_timestamp) /1000
            
#             if diff < 0.250: # this means it was pressed fast
#                 # button_id = hex(MatrixEvent.key_number+1)
#                 # data_out["buttons"] = [{"id": button_id}]
#                 # data_out["button_id"] = button_id
#                 print(f"ashdashda, {diff}")
#                 # data_out["Button_id"] = MatrixEvent.key_number+1
#                 data_out["Button_id"] = event.key_number+1

#             else: # the buton was held for over 0.250 seconds 
#                 # held_keys[MatrixEvent.key_number]  = 0
#                 held_keys[event.key_number]  = 0
#                 return

#         # held_keys[MatrixEvent.key_number]  = 0
#         held_keys[event.key_number]  = 0
    
#     elif type == "rotary encoder": #look at the encoder vars list, which would be ordered as ["name", ChangeInPosition, buttonState],  
#         # print(encoder_pos_change > 0)
#         # print(encoder_pos_change, encoder_button)
        
#         # encoder = hex(event[-1])
#         encoder = int(event[-1])
#         # 0 for left and 1 for right,  left is negative and right is positive
#         if encoder_pos_change < 0:
#             encoder_val = "RL"
#         else:
#             encoder_val = "RR"
#         if encoder_button:
#             encoder_val+="B"
        
#         data_out["Encoder"] = [{'Id': encoder, 'Value': encoder_val}]
    
#     layers = []
#     #on to layers now      
#     for index, timestamp in enumerate(held_keys):
#         if timestamp:
#             #if there is a button  that is being held
#             diff = (supervisor.ticks_ms() - timestamp)/1000
#             if diff > 0.100: 
#                 if index == 12:
#                     # button_id = '0x0'
#                     button_id = 'Mode'
#                 else:
#                     # button_id = hex(index+1)
#                     button_id = index+1
#                 layers.append(button_id)

#     if len(layers) !=0:
#         data_out["Layers"] = layers 
#     print(json.dumps(data_out))
    
#     pixels[14] = (0, 255, 0)
#     pixels.show()
#     time.sleep(0.05)
#     pixels[14] = (0, 0, 0)
#     pixels.show()


def msgContructor3(event, type, encoder_button: int = 0, encoder_pos_change: int = 0 ):
    data_out = {}
    if type == "mode": 
        if held_keys_dict["Mode"]:  # I dont think this needs to be here
            timestamp = held_keys_dict["Mode"]
            diff = (supervisor.ticks_ms() - timestamp)/1000
            if diff < 0.250:   # if its less then
                data_out["Button_id"] =  'Mode'
            else:
                held_keys_dict.pop("Mode")
                # held_keys[-1]  = 0
                return 
        
        held_keys_dict.pop("Mode")

    elif type == "button":
        key_timestamp = held_keys_dict[event.key_number]

        if key_timestamp:
            diff = (supervisor.ticks_ms() - key_timestamp) /1000
            
            if diff < 0.250: # this means it was pressed fast
                # data_out["Button_id"] = MatrixEvent.key_number+1
                data_out["Button_id"] = event.key_number+1

            else: # the buton was held for over 0.250 seconds 
                # held_keys[MatrixEvent.key_number]  = 0
                held_keys_dict.pop(event.key_number)
                # held_keys[event.key_number]  = 0
                return
        held_keys_dict.pop(event.key_number)
    
    elif type == "rotary encoder": #look at the encoder vars list, which would be ordered as ["name", ChangeInPosition, buttonState],  

        encoder = int(event[-1])
        # 0 for left and 1 for right,  left is negative and right is positive
        if encoder_pos_change < 0:
            encoder_val = "RL"
        else:
            encoder_val = "RR"
        if encoder_button:
            encoder_val+="B"
        
        data_out["Encoder"] = [{'Id': encoder, 'Value': encoder_val}]
    
    layers = []
    #on to layers now      
    for key, timestamp in held_keys_dict.items():
        #if there is a button  that is being held
        diff = (supervisor.ticks_ms() - timestamp)/1000
        if diff > 0.100: 
            if key == "Mode":
                # button_id = '0x0'
                button_id = 'Mode'
            else:
                # button_id = hex(index+1)
                button_id = key+1
            layers.append(button_id)
            
    if len(layers) !=0:
        data_out["Layers"] = layers 
    print(json.dumps(data_out))
    
    pixels[14] = (0, 255, 0)
    pixels.show()
    time.sleep(0.05)
    pixels[14] = (0, 0, 0)
    pixels.show()

# async def layer_color_changer():
#     # await asyncio.sleep(0.100)
#     #await asyncio.sleep(0.130)
#     wait = 0.100
#     await asyncio.sleep(wait)
#     #time.sleep(wait)
#     #0.250
#     #print(f"have sleeped for {wait} secs")
#     for index, key in enumerate(held_keys):
#         #print(key)
#         if key != 0:  # if any var is not 0

#             #if there is a button  that is being held
#             diff = ((supervisor.ticks_ms() - key)/1000)#-wait
#             # print(diff)
#             # takes the current time - var div by 1000
#             # if diff > 0.100: # if the diff is greater then 0.1s, ie been pressed for more then 0.1s 
#             if diff > wait: # if the diff is greater then 0.1s, ie been pressed for more then 0.1s 
#                 # print(f"diff is greater then {wait} for {key}, changing color {held_keys.index(key)}, {index}, {diff}")
#                 pixels[index] = (255,0,0)
#                 pixels.show()        
            
            
            
            
#     # for i in held_keys: #loops through all the items in held_keys list
#     #     print(i)
#     #     if i != 0:  # if any var is not 0
#     #         #if there is a button  that is being held
#     #         diff = (supervisor.ticks_ms() - i)/1000
#     #         # takes the current time - var div by 1000
#     #         if diff > 0.100: # if the diff is greater then 0.1s, ie been pressed for more then 0.1s 
#     #             #changes coolor to yellow
#     #             # pixels[held_keys.index(i)] = (255,255,0)
#     #             print(f"diff is greater then 0.100 for {i}, changing color {held_keys.index(i)}")
#     #             pixels[held_keys.index(i)] = (255,0,0)
#     #             pixels.show()

# async def layer_color_changer2(min_diff = 0.100, key = None):
#     if key is not None:
#         timestamp  = held_keys_dict[key]
#         diff = ((supervisor.ticks_ms() - timestamp)/1000)
#         # takes the current time - var div by 1000
#         if diff > min_diff: # if the diff is greater then 0.1s, ie been pressed for more then 0.1s 
#             print(f"greater then2, {diff}")
#             print(supervisor.ticks_ms())
#             if key =="Mode":
#                 pixels[12] = (255,0,0)
#             else:
#                 pixels[key] = (255,0,0)
#             # pixels[key] = (255,0,0)
#             pixels.show()  
#             time.sleep(0.05)
#         return
    
    
#     # await asyncio.sleep(min_diff)
    
#     # await asyncio.sleep(0.100)
#     for key, timestamp in held_keys_dict.items():
#         print(key, timestamp) 
    
#         diff = ((supervisor.ticks_ms() - timestamp)/1000)
#         # takes the current time - var div by 1000
#         if diff > min_diff: # if the diff is greater then 0.1s, ie been pressed for more then 0.1s 
#             print(f"greater then1, {diff}, ")
#             print(supervisor.ticks_ms())
            
#             if key =="Mode":
#                 pixels[12] = (255,0,0)
#             else:
#                 pixels[key] = (255,0,0)
#             pixels.show()       

    
#     if diff < (min_diff+0.010):
#         print("sda")
#         await asyncio.sleep(min_diff)
#         asyncio.run(layer_color_changer2(key=key))
        

################################################################
# loop-y-loop
################################################################

def main():
    encoder_1_last_position = 0
    encoder_2_last_position = 0 

    
    while True:
        # add to that dictionary to send the data at the end of the loop
        # data_out = {}

        ################################################################
        # Data sent from computer
        ################################################################
        # read the REPL serial line by line when there's data
        if supervisor.runtime.serial_bytes_available:
            data_in = serial.readline()

            # try to convert the data to a dict (with JSON)
            data = None
            if len(data_in) > 0:
                try:
                    data = json.loads(data_in)
                except ValueError:
                    data = {"raw": data_in}

            
            # interpret
            if isinstance(data, dict):
                onboard_pix.fill((0, 255, 0))
                
                if "color" in data:
                    color_data = data["color"]
                    if color_data[0] == 'All':
                        pixels.fill(color_data[1])
                    else:
                        pixels[int(color_data[0])] = color_data[1]
                    pixels.show()
                    
                onboard_pix.fill((0, 0, 0))
        
        
        ################################################################
        # Encoders
        ################################################################
        encoder_1_position = encoder_1.position
        encoder_2_position = encoder_2.position
        if encoder_1_last_position is None or encoder_1_position != encoder_1_last_position:
            # led.value = True
            encoder_1_position_change = encoder_1_position - encoder_1_last_position

            msgContructor3("Encoder1", "rotary encoder", not encoder_1_button.value, encoder_1_position_change)
            time.sleep(0.1)
            # led.value = False


        encoder_1_last_position = encoder_1_position

        if encoder_2_last_position is None or encoder_2_position != encoder_2_last_position:
            # led.value = True
            encoder_2_position_change = encoder_2_position -  encoder_2_last_position

            msgContructor3("Encoder2", "rotary encoder", not encoder_2_button.value, encoder_2_position_change)
            time.sleep(0.1)
            # led.value = False


        encoder_2_last_position = encoder_2_position

        # if not encoder_1_button.value and encoder_1_button_state is None:
        #     encoder_1_button_state = "pressed"
        #     print("Button pressed.")
        # if encoder_1_button.value and encoder_1_button_state == "pressed":
        #     print("Button released.")
        #     encoder_1_button_state = None
        
        ################################################################
        # Buttons
        ################################################################
        if MatrixEvent := keys.events.get():
            # this is the main 4x3 key grid.
            
            if MatrixEvent.pressed:
                # when the button is pressed, all I want it to do is put the time stamp in he held_keys list 
                
                held_keys_dict[MatrixEvent.key_number] = MatrixEvent.timestamp

                ### A barebones test for changing colors if its a layer
                pixels[MatrixEvent.key_number] = (0, 255, 0)        #turns it green
                pixels.show()
                
                
                # print(f"pressed {MatrixEvent.key_number} at {MatrixEvent.timestamp}")
                # asyncio.run(layer_color_changer2())
                for key, timestamp in held_keys_dict.items():
                    diff = (supervisor.ticks_ms() - timestamp)/1000
                    if diff > 0.100: 
                        if key =="Mode":
                            pixels[12] = (255,0,0)
                        else:
                            pixels[key] = (255,0,0)
                        pixels.show()       
        
            if MatrixEvent.released:
                # print(f"released {MatrixEvent.key_number} at {MatrixEvent.timestamp}")
                
                msgContructor3(MatrixEvent, 'button')
            
                pixels[MatrixEvent.key_number] = (0, 0, 0)
                pixels.show()


        if ModeEvent := ModeButton.events.get():
            # this is the mode button
            if ModeEvent.pressed:
                # pixels[12] = (255, 0, 0)
                pixels[12] = (0, 255, 0)
                pixels.show()
                held_keys_dict["Mode"] = ModeEvent.timestamp
                
                
                # asyncio.run(layer_color_changer2())
                
            if ModeEvent.released:
                msgContructor3(ModeEvent, "mode")
                
                pixels[12] = (0, 0, 0)
                pixels.show()

def startup():
    pixels.fill((0,255,0))
    pixels.show()
    
    time.sleep(0.25)
    
    pixels.fill((255,0,255))
    pixels.show()
    
    time.sleep(0.25)
    
    pixels.fill((0,0,0))
    pixels.show()
    time.sleep(0.25)
    
    pixels.fill((0,255,0))
    pixels.show()
    
    time.sleep(0.25)
    
    pixels.fill((0,0,0))
    pixels.show()
    
    time.sleep(0.25)
    pixels.fill((255,0,255))
    pixels.show()
    
    time.sleep(0.25)
    pixels.fill((0,0,0))
    pixels.show()
    
if __name__ == "__main__":
    startup()
    
    main()

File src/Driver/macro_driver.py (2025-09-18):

#from . import setup
from setup import logger, send_notification, file_dir, config, version, plat
#config = setup.config
import macros
import pystray
from PIL import Image
import threading
import serial.tools.list_ports
import time
import json

Spotify = macros.SpotifyController()
FireFox = macros.FireFoxController()

class MacroDriver:
    def __init__(self, baud_rate = 115200, mode = 1):
        self.baud_rate = baud_rate
        self.mode = mode
        self.port = None
        self.run = True
        self.pause_state = False
        self.focused_window_hwnd = None
        self.channel = None
        self.device = "KB2040 - CircuitPython"
        self.recursion_count = 0
             
    def update_mode(self):
        self.mode += 1
        if self.mode == 3:
            self.mode = 1
        logger.info(f'Mode is now {self.mode}')

    # It is to prevent my dad from pressing all the buttons and messing things up
    def on_pause(self, state):
        logger.info(f'Pause is set to: {state}')
        self.pause_state = state
        
    def change_pause_state(self):
        #self.pause_state = not self.pause_state
        if self.pause_state:
            self.pause_state =  False
            color = (0,0,0)
            
        else:
            self.pause_state = True
            color = (255,0,0)
                    
        data = {"color": [13,color]}
        self.write_serial(data)
        logger.info(f'Pause is set to: {self.pause_state}')

    def stop(self):
        self.run = False 
        if self.serial_port:
            self.serial_port.close()

    def find_device_serial_port(self, name):
        device_ports = [port.device 
                        for port in serial.tools.list_ports.comports()
                        if name in port.description]
        return device_ports
    
    def setup_serial(self):
        """
        Helper to connect and reconnet to the serial channel
        """
        
        if self.port is None:
            logger.info("getting port")
            ports = self.find_device_serial_port(self.device)
            
            #if not ports:
            if len(ports) == 0:
                logger.info(f'at {self.recursion_count} recursions')
                logger.info('No KB2040 found in comports. Retrying in 5 seconds...')
                time.sleep(5)
                self.recursion_count +=1
                
                # temporary fix to to many recursions
                if self.recursion_count == 500:
                    self.recursion_count=0
                    return 
                
                self.setup_serial()
                # continue    
            elif len(ports) > 0:
                self.port = ports[0]
                self.recursion_count=0
                
        try:
            #global channel
            if self.channel is None:
     
                self.channel = serial.Serial(self.port, self.baud_rate)
                self.channel.timeout = 0.05
                
                logger.info(f'Connected to serial port {self.port} at {self.baud_rate} baud')
                send_notification(title='Connected', msg='Connected to Arduino succesfully!')
       
        except serial.serialutil.SerialException:
            # logger.warning("SerialException(2, could not open port")
            # self.port = None    
            logger.critical('Arduino is already connected to something, shutingdown')
            send_notification(title='Access is denied', msg='Access is denied! Arduino is already connected to something', urgency='critical')
            self.stop()    
            
        # except IndexError:
        #     logger.warning("The Microcontroller is not connected to the computer")
                
        except FileNotFoundError as ex:
            logger.warning(ex)
            self.port = None
            
        
        except Exception as ex:
            logger.warning(ex)
            self.channel = None
                
        return self.channel

    def error_serial(self):
        """
        Helper to handle serial errors
        """
        logger.error("Exception on read, did the board disconnect?")
        #global channel
        if self.channel is not None:
            logger.error("Closing Connection to Microcontroller.")
            self.channel.close()
            self.channel = None
        
            logger.error("Changing serial Port Variable, will have to get new one.")
            
            self.port = None

    def read_serial(self):
        while self.run:
            self.setup_serial()
            
            line = None
            try:
                #receives data from microcontroller
                line = self.channel.readline()[:-2]
            except KeyboardInterrupt:
                logger.critical("KeyboardInterrupt - quitting")
                exit()
                
            except Exception as ex:
                logger.error(ex)
                #logger.error("The Microcontroller probably disconected.")    
                self.error_serial()
                time.sleep(1)
                continue

            if line != b"":
                try:
                    data = json.loads(line.decode("utf8"))
                except Exception as ex:
                    logger.warning(ex)
                    data = {"raw": line.decode("utf8")}
                    #print(data)
            
                if "raw" in data:
                    logger.debug(data)
                    continue
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

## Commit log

2022-12-06 Bug Fixes and QOL improvements
    [MacroV2.0.0.py, MacroV2.1.0.py, MacroV2.2.0.py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]
2022-12-13 Runs Task Manager when button 8 is pressed
2023-03-01 Removed TTS and fixed a bug in spotifyV2
    [MacroV2.3.1.py, funcs.py]
2023-03-02 Fixed Text To Speech and added a stop Speech
    [MacroV2.3.1.py, funcs.py]
2023-03-02 Fixed bug with tts
    [MacroV2.3.1.py, funcs.py]
2023-03-07 minor fix, added func timer but is commented out
    [MacroV3.0.py]
2023-03-10 Fixed an issue with spotifyV2 and added to TODO
    [MacroV3.0.py]
2023-04-11 Added arduino code. CODE WILL NOT WORK
    [arduino_code.ino, arduino_test.ino.ino, macro_driver.py]
2023-04-11 Arduino Code testing
2023-04-12 Working on Arduino code
2023-07-08 Updated Button Mode text
2023-07-08 Added arduino code to V3.2
2023-12-20 Repository Structure Update
    [bom.csv, designators.csv, macrov2.0.001.kicad_pcb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]
2023-12-21 PCB revisions, Newest is in production
    [ads.dsn, ads.kicad_pcb, ads.kicad_sch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]
2024-01-09 Update readme.md
    PCB assembled and mistakes made when designing it.
2024-04-02 Macro Driver now works like Prev Version.
2024-04-02 Driver Will now connect to macro
2024-04-02 Fixed Chrome Audio Controller Actions dict
    [tools.py]
2024-04-02 Changed click time in Image_to_text2
    [macrov2.0.004.kicad_sch]
2024-04-02 Added Zoom in and Zoom out funcs to encoder2
    [LEDtest.kicad_pcb, LEDtest.kicad_sch, macrov2.0.004.kicad_sch]
2024-04-02 OnboardLEd now turns on for encoders
2024-04-06 Removed code from Image_to_text2(), the onboard LED on Microcontroller now works
2024-04-06 New PCB Revision
    [bom.csv, designators.csv, macrov2.2.001.kicad_pcb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]
2024-04-16 v2.2.801 is a test, 2.2.001 is still the main one.
    [macrov2.2.001-B_Cu.gbr, macrov2.2.001-B_Mask.gbr, macrov2.2.001-B_Paste.gbr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]
2024-04-17 added image of PCB to README
2024-04-19 Repo Structure Change
    [LEDtest.kicad_pcb, LEDtest.kicad_sch, ads.dsn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]
2024-04-20 Added Case 3D model
    [V2.2 Case v2.stl]
2024-10-31 Small Updates
    [Top Plate V3.stl, bom.csv, designators.csv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]
2024-11-02 New Logging level and implemented Spotify.move_spotify_window()
    [Bottom_Case_No_Hole_V2.stl, Bottom_Case_with_hole_V2.stl, Top_Plate_V3.stl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]
2025-09-18 Added Soundboard funtionality, Temporary fix for recursion limit crash, temp disabled any window info func
    [_linux_macros.py, macro_driver.py, macros.py]
2026-01-14 2.4.002 Minor changes, Button Led show when its a layer.
